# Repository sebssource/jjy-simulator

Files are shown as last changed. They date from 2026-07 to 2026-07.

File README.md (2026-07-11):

# Fork notes

Warning: Vibe coded with Qwen 3.6 27B running on my local machine.

## Features
* split code into multiple files
* replaced Tailwind with raw CSS
* enabled cold boot/scheduled/permanent broadcast
* enabled scheduled/permanent on Wifi
* settings saved/restored automatically
* added FreeCAD source for a more generic case + lid (not vibe coded) and STL files

## My build notes
I used a 9mm X 100mm ferrite core and wound 80mm of 0.35mm enameled wire, leaving about 10mm clear at each end. Bought the same capacitors but measured about 1.7nF of capacitance so I redid the antenna math, changed the number of turns a bit (about 290) and it worked on the first try.

Tested with my Citizen PMD56-2952

## TODO
* some minor cleanup of the code and UI
* maybe daily schedule UI

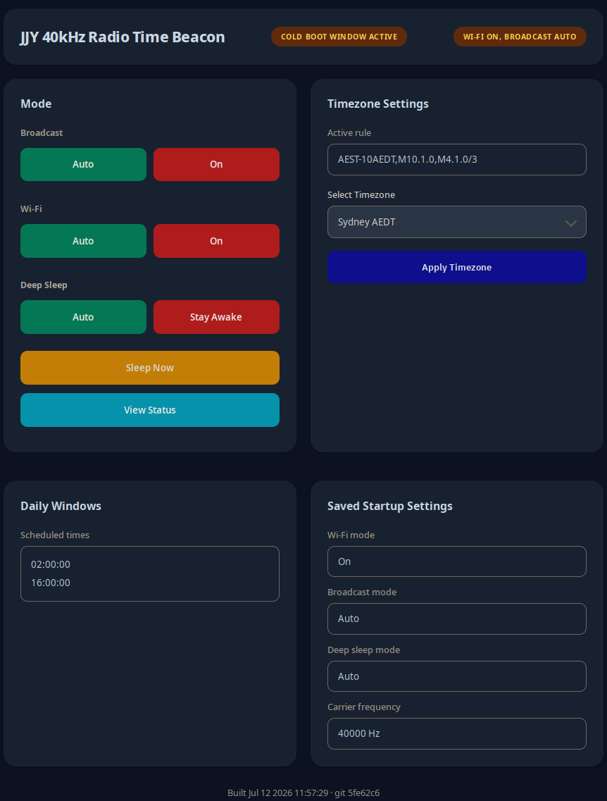
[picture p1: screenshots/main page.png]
Main page screenshot


--------------------------------
# JJY 40 kHz Simulator for ESP32

This project is a high-performance JJY (Fukushima 40 kHz) time signal simulator designed for ESP32 and the L9110S motor driver. It allows you to synchronize radio-controlled clocks (like those from Casio, Citizen, etc.) by simulating the Japanese JJY time signal.

Detailed project documentation and build log can be found here: [JJY Signal Simulator with ESP32 — 5m Range DIY Build](https://olafkrawczyk.com/journal/jjy-signal-simulator/)

## Motivation

Radio-controlled clocks designed for the Japanese market are often hardwired to listen only for the JJY longwave signal. Outside of Japan, these clocks cannot sync and must be set manually. This project "brings the signal to the clock" by creating a local transmitter that broadcasts the JJY protocol, allowing these "self-correcting" devices to function as intended anywhere in the world.

## Parts List

| Component | Specification / Detail |
| :--- | :--- |
| **Microcontroller** | ESP32 DevKitV1 (ESP-WROOM-32) |
| **Power Amplifier** | L9110S dual-channel motor driver |
| **Ferrite Core** | 2× 50mm NiZn ferrite rods (bonded to 100mm) |
| **Coil Wire** | ~11m enameled copper wire (~250–300 turns) |
| **Resonant Capacitor 1** | ~1.5 nF MKP film capacitor (Primary resonance) |
| **Resonant Capacitor 2** | ~100 pF ceramic disc capacitor (Fine-tuning/Trimming) |
| **Power** | Micro-USB cable + 5V supply |

## Hardware Setup

The project uses an "Antiphase drive" concept to increase the voltage swing across the transmission tank circuit.

- **MCU:** ESP32
- **Driver:** L9110S (or similar H-bridge)
- **Connections:**
  - `PIN_IA` (GPIO 25) -> L9110S IA
  - `PIN_IB` (GPIO 26) -> L9110S IB
  - `PIN_TX_LED` (GPIO 2/Built-in) -> Transmission status LED

### Wiring Diagram

#### Physical Layout (ASCII)
```text
      ESP32 DevKit                L9110S Driver
    +--------------+            +--------------+
    |   [USB]      |            |              |
    |          VIN |------------| VCC (5V)     |
    |          GND |------------| GND          |
    |      GPIO 25 |------------| IA           |
    |      GPIO 26 |------------| IB           |
    +--------------+            |              |
                                |   OA    OB   |
                                +---|-----|----+
                                    |     |
            +-----------------------+     |
            |                             |
            |     +-------+-------+       |
            +-----|  COIL |  C1   |  C2   |
            |     | (Ant) | 1.5nF | 100pF |
            +-----|       |       |       |
            |     +-------+-------+       |
            |       (Parallel Tank)       |
            +-----------------------------+
```

#### Schematic Flow (Mermaid)
```mermaid
graph LR
    subgraph "Control Logic"
        ESP[ESP32 DevKit]
        P25[GPIO 25]
        P26[GPIO 26]
        VIN[5V / VIN]
        GND[GND]
    end

    subgraph "Power Stage (L9110S)"
        DRV((H-Bridge))
        IA[IA]
        IB[IB]
        OA[OA]
        OB[OB]
        VCC[VCC]
        DGND[GND]
    end

    subgraph "Resonant Antenna (40 kHz)"
        ANT[Ferrite Coil]
        C1[Capacitor 1.5nF]
        C2[Capacitor 100pF]
    end

    %% Wiring
    P25 --- IA
    P26 --- IB
    VIN --- VCC
    GND --- DGND

    %% Tank Circuit (Parallel)
    OA --- ANT
    OA --- C1
    OA --- C2
    
    OB --- ANT
    OB --- C1
    OB --- C2

    style ANT fill:#f9f,stroke:#333,stroke-width:2px
    style C1 fill:#bbf,stroke:#333
    style C2 fill:#bbf,stroke:#333
    style DRV fill:#dfd,stroke:#333
```

### Simplified Pin Mapping

| ESP32 Pin | L9110S Pin | Notes |
| :--- | :--- | :--- |
| GPIO 25 | IA | PWM Signal A |
| GPIO 26 | IB | PWM Signal B (Inverted) |
| GND | GND | Common Ground |
| VIN (5V) | VCC | Driver Power |
| - | OA | Antenna Out A |
| - | OB | Antenna Out B |

## Configuration

Before flashing, create a `include/secrets.h` file based on `include/secrets.h.example` and fill in your WiFi credentials:

```cpp
#ifndef SECRETS_H
#define SECRETS_H

#define WIFI_SSID "your_ssid"
#define WIFI_PASS "your_password"

#endif
```

## Features

- **Antiphase PWM Drive:** 40 kHz carrier frequency with configurable duty cycle.
- **NTP Synchronization:** Automatically fetches precise time from NTP servers.
- **Scheduled Transmissions:** Configurable transmission slots throughout the day.
- **Web Interface:** Basic web UI for status monitoring and frequency adjustment.
- **Deep Sleep:** Power-saving mode between scheduled transmission slots.

## License

This project is licensed under the MIT License - see the [LICENSE](LICENSE) file for details.

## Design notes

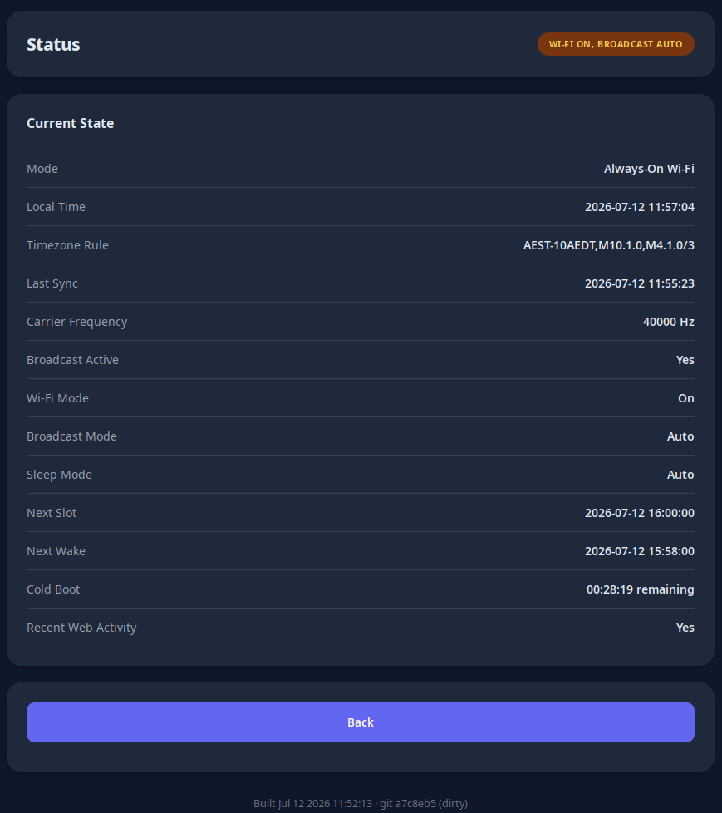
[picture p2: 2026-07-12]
screenshots/status page.png

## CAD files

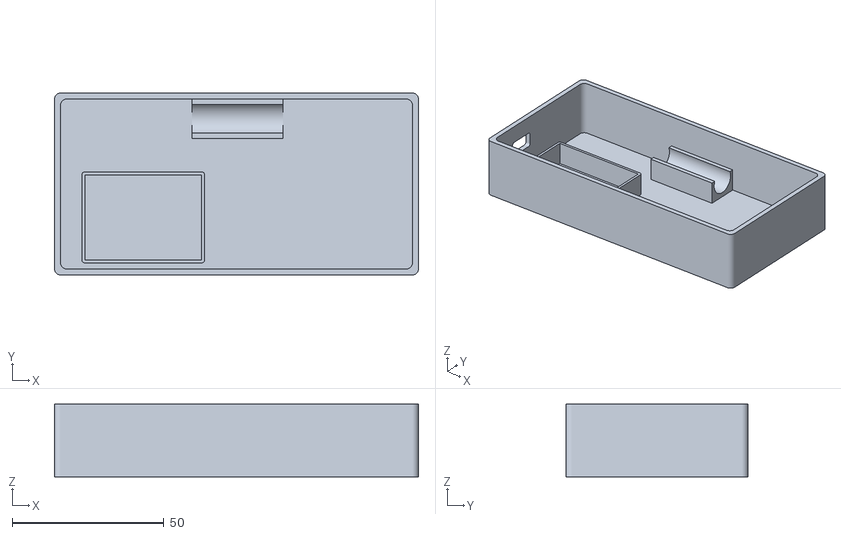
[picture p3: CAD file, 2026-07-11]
case/JJY case-Body.stl
120.0 x 60.0 x 24.0

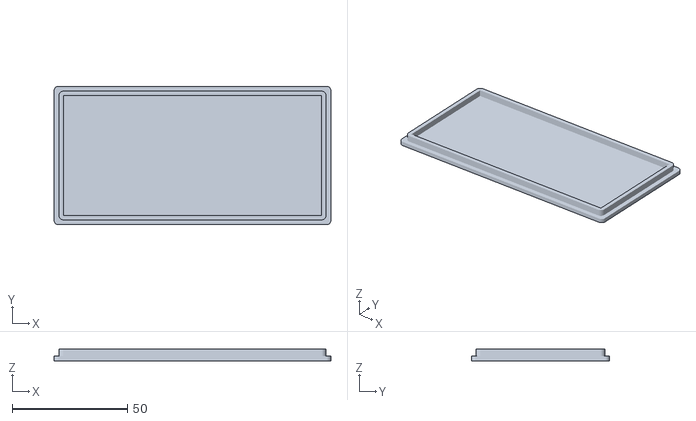
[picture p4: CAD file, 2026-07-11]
case/JJY case-Lid.stl
120.0 x 60.0 x 5.00

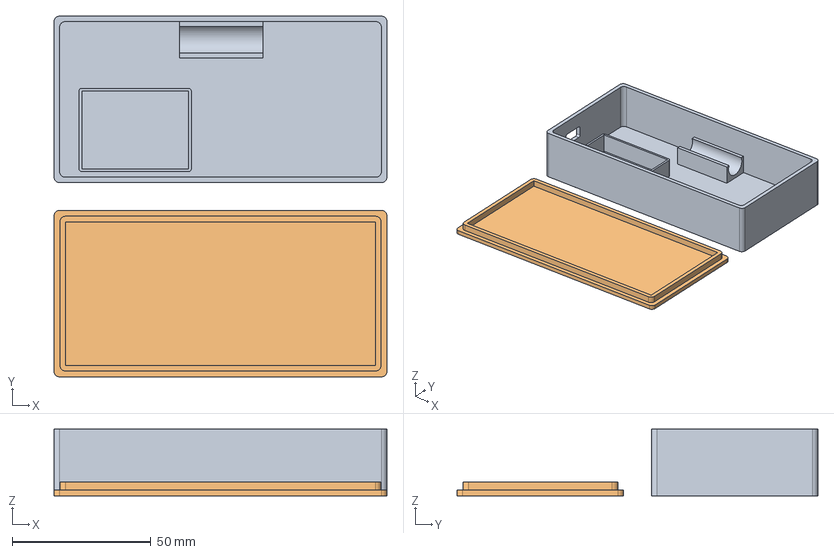
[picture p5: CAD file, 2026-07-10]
case/JJY case.FCStd
120.0 x 130.0 x 24.0 mm
Lid

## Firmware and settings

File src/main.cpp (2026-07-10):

#include "carrier.h"
#include "jjy.h"
#include "scheduler.h"
#include "shared_state.h"
#include "web_server.h"
#include "wifi_time.h"
#include <Arduino.h>
#include <WiFi.h>
#include <esp_sleep.h>

/*
  JJY 40 kHz simulator (Fukushima frequency) for ESP32 + L9110S.

  Antiphase drive concept:
  - IA and IB are both 40 kHz square waves (target duty configurable, default 45%).
  - IB is the inverted PWM waveform (~180 deg relative to IA).
  - Across the tank (between OA and OB), voltage swing is increased vs single-ended GPIO.

  Modulation method:
  - Carrier ON  = both PWM channels active.
  - Carrier OFF = duty set to 0 on both channels.
*/

void handleSerialCommands()
{
    while (Serial.available() > 0) {
        const char c = static_cast<char>(Serial.read());
        switch (c) {
        case '+':
            setCarrierFrequency(static_cast<uint32_t>(static_cast<int32_t>(currentCarrierHz) + static_cast<int32_t>(CARRIER_HZ_STEP)), true);
            break;
        case '-': {
            int32_t nextHz = static_cast<int32_t>(currentCarrierHz) - static_cast<int32_t>(CARRIER_HZ_STEP);
            if (nextHz < 0) {
                nextHz = 0;
            }
            setCarrierFrequency(static_cast<uint32_t>(nextHz), true);
        } break;
        case '?':
            Serial.printf("[PWM] Frequency=%lu Hz, Range=%lu..%lu, Step=%lu\n", currentCarrierHz, CARRIER_HZ_MIN, CARRIER_HZ_MAX, CARRIER_HZ_STEP);
            break;
        case '\r':
        case '\n':
        case ' ':
        case '\t':
            break;
        default:
            Serial.printf("[PWM] Unknown cmd '%c'. Use + / - / ?\n", c);
            break;
        }
    }
}

void runJjySchedulerTick()
{
    handleSerialCommands();
    updateCarrierRamp();

    if (!txWindowActive) {
        if (symbolOnPhaseActive || carrierIsOn) {
            carrierOff();
            symbolOnPhaseActive = false;
        }
        return;
    }

    tm nowLocal;
    if (!getCurrentLocalTime(nowLocal)) {
        carrierOff();
        symbolOnPhaseActive = false;
        return;
    }

    if (shouldRebuildFrame(nowLocal)) {
        buildJjyFrame(nowLocal);
        Serial.printf("[FRAME] rebuilt for %04d-%03d %02d:%02d (current TZ)\n",
            nowLocal.tm_year + 1900,
            dayOfYear(nowLocal),
            nowLocal.tm_hour,
            nowLocal.tm_min);
    }

    if (nowLocal.tm_sec != currentSecond) {
        currentSecond = nowLocal.tm_sec;
        transmitSecond(nowLocal, currentSecond);
    }

    if (symbolOnPhaseActive) {
        const uint32_t elapsedOnMs = millis() - symbolOnStartedMs;
        if (!rampDownStartedForSymbol && activeOnDurationMs > CARRIER_RAMP_TOTAL_MS) {
            const uint32_t rampDownStartMs = activeOnDurationMs - CARRIER_RAMP_TOTAL_MS;
            if (elapsedOnMs >= rampDownStartMs) {
                beginCarrierRampDown();
            }
        }

        if (elapsedOnMs >= activeOnDurationMs) {
            carrierOff();
            symbolOnPhaseActive = false;
        }
    }
}

void jjyTask(void* arg)
{
    (void)arg;
    TickType_t lastWake = xTaskGetTickCount();

    for (;;) {
        runJjySchedulerTick();
        vTaskDelayUntil(&lastWake, pdMS_TO_TICKS(JJY_TASK_PERIOD_MS));
    }
}

void networkTask(void* arg)
{
    (void)arg;

    for (;;) {
        if (WiFi.status() != WL_CONNECTED) {
            connectWifiStep();
        }
        periodicResync();
        vTaskDelay(pdMS_TO_TICKS(NET_TASK_PERIOD_MS));
    }
}

void setup()
{
    Serial.begin(115200);
    delay(200);
    Serial.println("\nJJY 40kHz simulator starting...");

    const esp_sleep_wakeup_cause_t wakeCause = esp_sleep_get_wakeup_cause();
    const bool isColdBoot = wakeCause != ESP_SLEEP_WAKEUP_TIMER;
    Serial.printf("[BOOT] Wake cause: %d\n", static_cast<int>(wakeCause));

    coldBootStartupPending = isColdBoot;
    coldBootBroadcastActive = false;

    pinMode(PIN_TX_LED, OUTPUT);
    setTxLed(false);
    Serial.printf("[IO] TX LED GPIO%d\n", PIN_TX_LED);

    prefsReady = prefs.begin(NVS_NS, false);
    if (!prefsReady) {
        Serial.println("[NVS] Preferences begin failed. Using default settings.");
    } else {
        const uint32_t savedHz = prefs.getUInt(NVS_KEY_FREQ, CARRIER_HZ_DEFAULT);
        currentCarrierHz = clampCarrierHz(savedHz);
        currentTzRule = prefs.getString(NVS_KEY_TZ, currentTzRule);
        loadModeState();

        if (savedHz != currentCarrierHz) {
            saveCarrierHzToNvs(currentCarrierHz);
        }
        Serial.printf("[NVS] Loaded carrier frequency: %lu Hz\n", currentCarrierHz);
        Serial.printf("[NVS] Loaded timezone rule: %s\n", currentTzRule.c_str());
    }

    setupCarrier();
    Serial.printf("[PWM] Soft ramp enabled: up/down %lums with %u steps\n", CARRIER_RAMP_TOTAL_MS, CARRIER_RAMP_STEP_COUNT);
    connectWifi();

    if (!initialTimeSync()) {
        Serial.println("[NTP] Continuing; will retry while keeping carrier OFF until time is valid.");
        lastResyncAttemptMs = 0;
    }

    setupWebServer();

    if (coldBootStartupPending) {
        if (modeState.broadcastMode == BroadcastMode::ON) {
            coldBootStartupPending = false;
            Serial.println("[BOOT] Permanent broadcast active; skipping cold-boot broadcast window.");
        } else {
            const time_t nowEpoch = time(nullptr);
            if (isValidEpoch(nowEpoch)) {
                startColdBootBroadcastWindow(nowEpoch);
            } else {
                Serial.println("[BOOT] Cold-boot broadcast pending until time becomes valid.");
            }
        }
    }

    xTaskCreatePinnedToCore(jjyTask,
        "jjy_tx",
        JJY_TASK_STACK_WORDS,
        nullptr,
        JJY_TASK_PRIORITY,
        &jjyTaskHandle,
        JJY_TASK_CORE);

    xTaskCreatePinnedToCore(networkTask,
        "net_maint",
        NET_TASK_STACK_WORDS,
        nullptr,
        NET_TASK_PRIORITY,
        &netTaskHandle,
        NET_TASK_CORE);

    Serial.printf("[TASK] JJY task core=%d prio=%u, NET task core=%d prio=%u\n",
        static_cast<int>(JJY_TASK_CORE),
        static_cast<unsigned>(JJY_TASK_PRIORITY),
        static_cast<int>(NET_TASK_CORE),
        static_cast<unsigned>(NET_TASK_PRIORITY));
}

void loop()
{
    if (webServerReady && WiFi.status() == WL_CONNECTED) {
        webServer.handleClient();
    }

    updateScheduler();
    delay(MAIN_LOOP_PERIOD_MS);
}

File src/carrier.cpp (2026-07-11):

#include "carrier.h"

#include <Preferences.h>
#include <driver/mcpwm_prelude.h>

#include "shared_state.h"

static mcpwm_timer_handle_t s_timer = nullptr;
static mcpwm_oper_handle_t s_oper = nullptr;
static mcpwm_cmpr_handle_t s_cmpr = nullptr;
static mcpwm_gen_handle_t s_genA = nullptr;  // GPIO PIN_IA
static mcpwm_gen_handle_t s_genB = nullptr;  // GPIO PIN_IB

static uint32_t timerPeriodTicks()
{
    return MCPWM_APB_CLK_HZ / currentCarrierHz;
}

uint32_t clampCarrierHz(uint32_t hz)
{
    if (hz < CARRIER_HZ_MIN) {
        return CARRIER_HZ_MIN;
    }
    if (hz > CARRIER_HZ_MAX) {
        return CARRIER_HZ_MAX;
    }
    return hz;
}

void saveCarrierHzToNvs(uint32_t hz)
{
    if (!prefsReady) {
        return;
    }
    prefs.putUInt(NVS_KEY_FREQ, hz);
}

// Recompute the comparator value for a given duty percentage (0..100) and
// apply it. Duty is expressed as a percentage of the timer period.
static void applyComparatorForDuty(float dutyPercent)
{
    const uint32_t period = timerPeriodTicks();
    uint32_t cmp;
    if (dutyPercent <= 0.0f) {
        cmp = period;  // compare never reached -> output stays low (off)
    } else {
        cmp = static_cast<uint32_t>(period * (dutyPercent / 100.0f));
        if (cmp == 0) {
            cmp = 1;
        }
        if (cmp >= period) {
            cmp = period - 1;
        }
    }
    mcpwm_comparator_set_compare_value(s_cmpr, cmp);
}

void reconfigureCarrierTimer(uint32_t hz)
{
    const bool wasOn = carrierIsOn;
    const mcpwm_timer_start_stop_cmd_t stopCmd = MCPWM_TIMER_STOP_FULL;
    const mcpwm_timer_start_stop_cmd_t startCmd = MCPWM_TIMER_START_NO_STOP;

    if (wasOn) {
        mcpwm_timer_start_stop(s_timer, stopCmd);
    }

    mcpwm_timer_set_period(s_timer, timerPeriodTicks());

    // Re-apply current duty (or off) at the new frequency.
    if (wasOn) {
        applyComparatorForDuty(CARRIER_DUTY_TARGET);
        mcpwm_timer_start_stop(s_timer, startCmd);
    } else {
        applyComparatorForDuty(0.0f);
    }
}

void setCarrierFrequency(uint32_t hz, bool persistToNvs)
{
    const uint32_t clampedHz = clampCarrierHz(hz);
    if (clampedHz == currentCarrierHz) {
        if (hz != clampedHz) {
            Serial.printf("[PWM] Frequency clamp hit: %lu Hz (range %lu..%lu)\n", clampedHz, CARRIER_HZ_MIN, CARRIER_HZ_MAX);
        }
        return;
    }

    reconfigureCarrierTimer(clampedHz);
    currentCarrierHz = clampedHz;
    if (persistToNvs) {
        saveCarrierHzToNvs(currentCarrierHz);
    }
    Serial.printf("[PWM] Current Frequency: %lu Hz\n", currentCarrierHz);
}

static uint32_t deadtimeNsToTicks(uint32_t ns)
{
    uint64_t ticks = (static_cast<uint64_t>(ns) * static_cast<uint64_t>(MCPWM_APB_CLK_HZ) + 999999999ULL) / 1000000000ULL;
    if (ticks == 0) {
        ticks = 1;
    }
    return static_cast<uint32_t>(ticks);
}

static void configureDeadtime()
{
    const uint32_t dtTicks = deadtimeNsToTicks(MCPWM_DEADTIME_NS);
    const mcpwm_dead_time_config_t dtCfg = {
        .posedge_delay_ticks = dtTicks,
        .negedge_delay_ticks = dtTicks,
        .flags = {
            .invert_output = 0,
        },
    };
    const esp_err_t err = mcpwm_generator_set_dead_time(s_genA, s_genB, &dtCfg);
    if (err == ESP_OK) {
        Serial.printf("[MCPWM] Dead-time enabled: %lu ns (~%lu ticks)\n", MCPWM_DEADTIME_NS, dtTicks);
    } else {
        Serial.printf("[MCPWM] Dead-time enable failed: err=%d\n", static_cast<int>(err));
    }
}

void setTxLed(bool on)
{
    digitalWrite(PIN_TX_LED, (on == TX_LED_ACTIVE_HIGH) ? HIGH : LOW);
}

void setupCarrier()
{
    const mcpwm_timer_config_t timerCfg = {
        .group_id = 0,
        .clk_src = MCPWM_TIMER_CLK_SRC_DEFAULT,
        .resolution_hz = MCPWM_APB_CLK_HZ,
        .count_mode = MCPWM_TIMER_COUNT_MODE_UP,
        .period_ticks = timerPeriodTicks(),
    };
    ESP_ERROR_CHECK(mcpwm_new_timer(&timerCfg, &s_timer));

    const mcpwm_operator_config_t operCfg = {
        .group_id = 0,
    };
    ESP_ERROR_CHECK(mcpwm_new_operator(&operCfg, &s_oper));
    ESP_ERROR_CHECK(mcpwm_operator_connect_timer(s_oper, s_timer));

    const mcpwm_comparator_config_t cmprCfg = {
        .flags = {
            .update_cmp_on_tez = true,
        },
    };
    ESP_ERROR_CHECK(mcpwm_new_comparator(s_oper, &cmprCfg, &s_cmpr));

    const mcpwm_generator_config_t genACfg = {
        .gen_gpio_num = PIN_IA,
    };
    const mcpwm_generator_config_t genBCfg = {
        .gen_gpio_num = PIN_IB,
    };
    ESP_ERROR_CHECK(mcpwm_new_generator(s_oper, &genACfg, &s_genA));
    ESP_ERROR_CHECK(mcpwm_new_generator(s_oper, &genBCfg, &s_genB));

    // Anti-phase drive: GEN_A high on timer EMPTY, low on COMPARE; GEN_B is the
    // complement (low on EMPTY, high on COMPARE).
    ESP_ERROR_CHECK(mcpwm_generator_set_action_on_timer_event(s_genA,
        MCPWM_GEN_TIMER_EVENT_ACTION(MCPWM_TIMER_DIRECTION_UP, MCPWM_TIMER_EVENT_EMPTY, MCPWM_GEN_ACTION_HIGH)));
    ESP_ERROR_CHECK(mcpwm_generator_set_action_on_compare_event(s_genA,
        MCPWM_GEN_COMPARE_EVENT_ACTION(MCPWM_TIMER_DIRECTION_UP, s_cmpr, MCPWM_GEN_ACTION_LOW)));
    ESP_ERROR_CHECK(mcpwm_generator_set_action_on_timer_event(s_genB,
        MCPWM_GEN_TIMER_EVENT_ACTION(MCPWM_TIMER_DIRECTION_UP, MCPWM_TIMER_EVENT_EMPTY, MCPWM_GEN_ACTION_LOW)));
    ESP_ERROR_CHECK(mcpwm_generator_set_action_on_compare_event(s_genB,
        MCPWM_GEN_COMPARE_EVENT_ACTION(MCPWM_TIMER_DIRECTION_UP, s_cmpr, MCPWM_GEN_ACTION_HIGH)));

    configureDeadtime();

    ESP_ERROR_CHECK(mcpwm_timer_enable(s_timer));
    ESP_ERROR_CHECK(mcpwm_timer_start_stop(s_timer, MCPWM_TIMER_START_NO_STOP));

    carrierOff();
    Serial.printf("[MCPWM] IA=GPIO%d, IB=GPIO%d, f=%lu Hz, anti-phase enabled\n", PIN_IA, PIN_IB, currentCarrierHz);
}

void applyCarrierDuty(float dutyPercent)
{
    float clampedDuty = dutyPercent;
    if (clampedDuty < 0.0f) {
        clampedDuty = 0.0f;
    }
    if (clampedDuty > CARRIER_DUTY_TARGET) {
        clampedDuty = CARRIER_DUTY_TARGET;
    }

    if (clampedDuty <= 0.0f) {
        applyComparatorForDuty(0.0f);
        carrierIsOn = false;
        setTxLed(false);
        return;
    }

    applyComparatorForDuty(clampedDuty);
    carrierIsOn = true;
    setTxLed(true);
}

void beginCarrierRampUp()
{
    rampUpActive = true;
    rampDownActive = false;
    rampStepIndex = 0;
    rampStepStartedMs = millis();
    applyCarrierDuty(CARRIER_RAMP_DUTY_STEPS[rampStepIndex]);
}

void beginCarrierRampDown()
{
    rampDownActive = true;
    rampUpActive = false;
    rampDownStartedForSymbol = true;
    rampStepIndex = CARRIER_RAMP_STEP_COUNT - 1;
    rampStepStartedMs = millis();
    applyCarrierDuty(CARRIER_RAMP_DUTY_STEPS[rampStepIndex]);
}
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

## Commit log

2026-05-22 Initial commit: JJY 40 kHz Simulator for ESP32
2026-07-08 Replaced Tailwind with raw CSS
    [main.cpp]
2026-07-09 Split code across multiple files. Reworked the UI
    [carrier.cpp, main.cpp, scheduler.cpp]
2026-07-10 Added FreeCAD case + lid source
    [JJY case.FCStd]
2026-07-10 Removed the Save button. Added AGENTS.md
2026-07-11 Added STL files and a screenshot
    [JJY case-Body.stl, JJY case-Lid.stl, JJY case.FCStd]
2026-07-11 Removed the esp32doit-devkit-v1 environment
2026-07-11 Added font consistency across the board
2026-07-11 Swapped status and sleep button colors
    [web_server.cpp]
